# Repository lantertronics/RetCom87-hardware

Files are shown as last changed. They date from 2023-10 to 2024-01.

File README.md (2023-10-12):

# RetCom87-hardware
These are expansion boards for the W65C265SXB development board by Western Design Center developed for the "RetCom87" homebrew computer project by my Retrofuturistic Hardware Vertically Integrated Project team at Georgia Tech. For details, see this YouTube playlist:

https://www.youtube.com/playlist?list=PLOunECWxELQQ03GeMmJSVX49A8VtCcbT9

Atari/Sega controller board: This works! See the Wiki for how to read the controller buttons and the example test code.

Sound board: The YM2149 soundchip board design has been tested on the breadboard, but the actual PCB hasn't been tested yet (I need to order it from JLCPCB). See the example test code.

Video board: The reset pin on TMS9118 is erroneously left disconnected on the PCB; I had to add a bodge wire to hook it to the W65C265SXB reset pin. The TMS9118 board currently sends out bright speckled video. I'm not sure what the issue is: https://youtu.be/yKsjV6f-HKg -- if anyone has any advice, please let me know: lanterma@ece.gatech.edu

These designs are dedicated to the public domain.

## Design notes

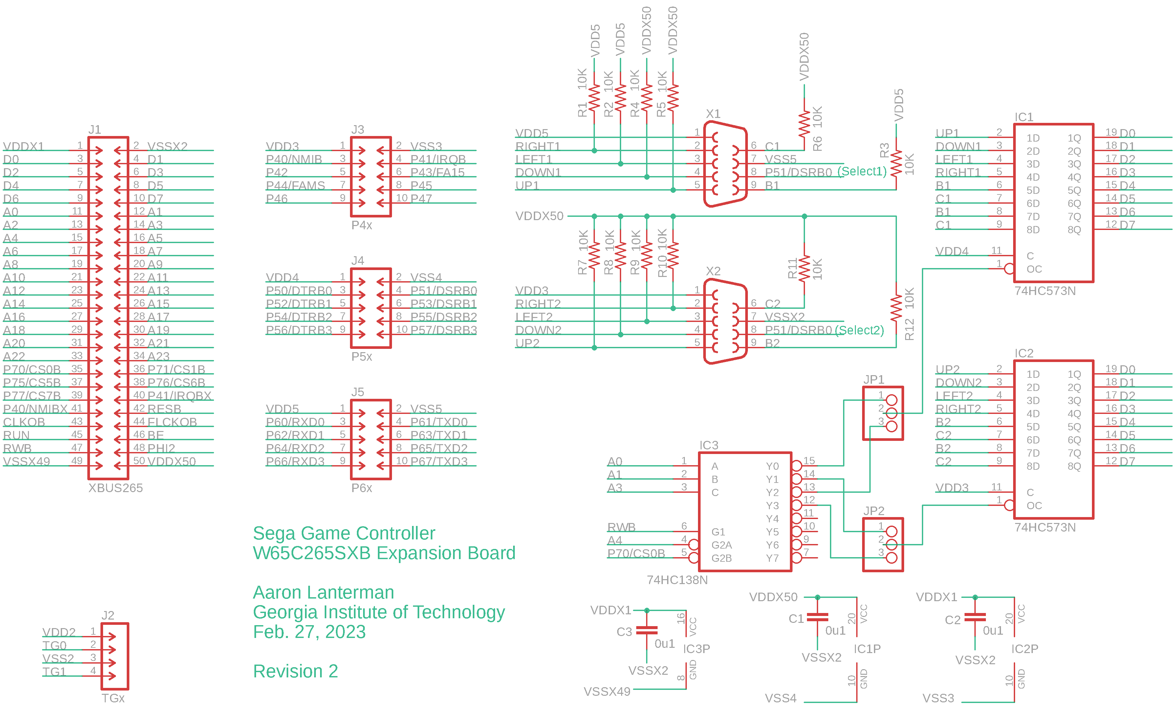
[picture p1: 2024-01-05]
w65c265sxb_controller_rev2_sch.png

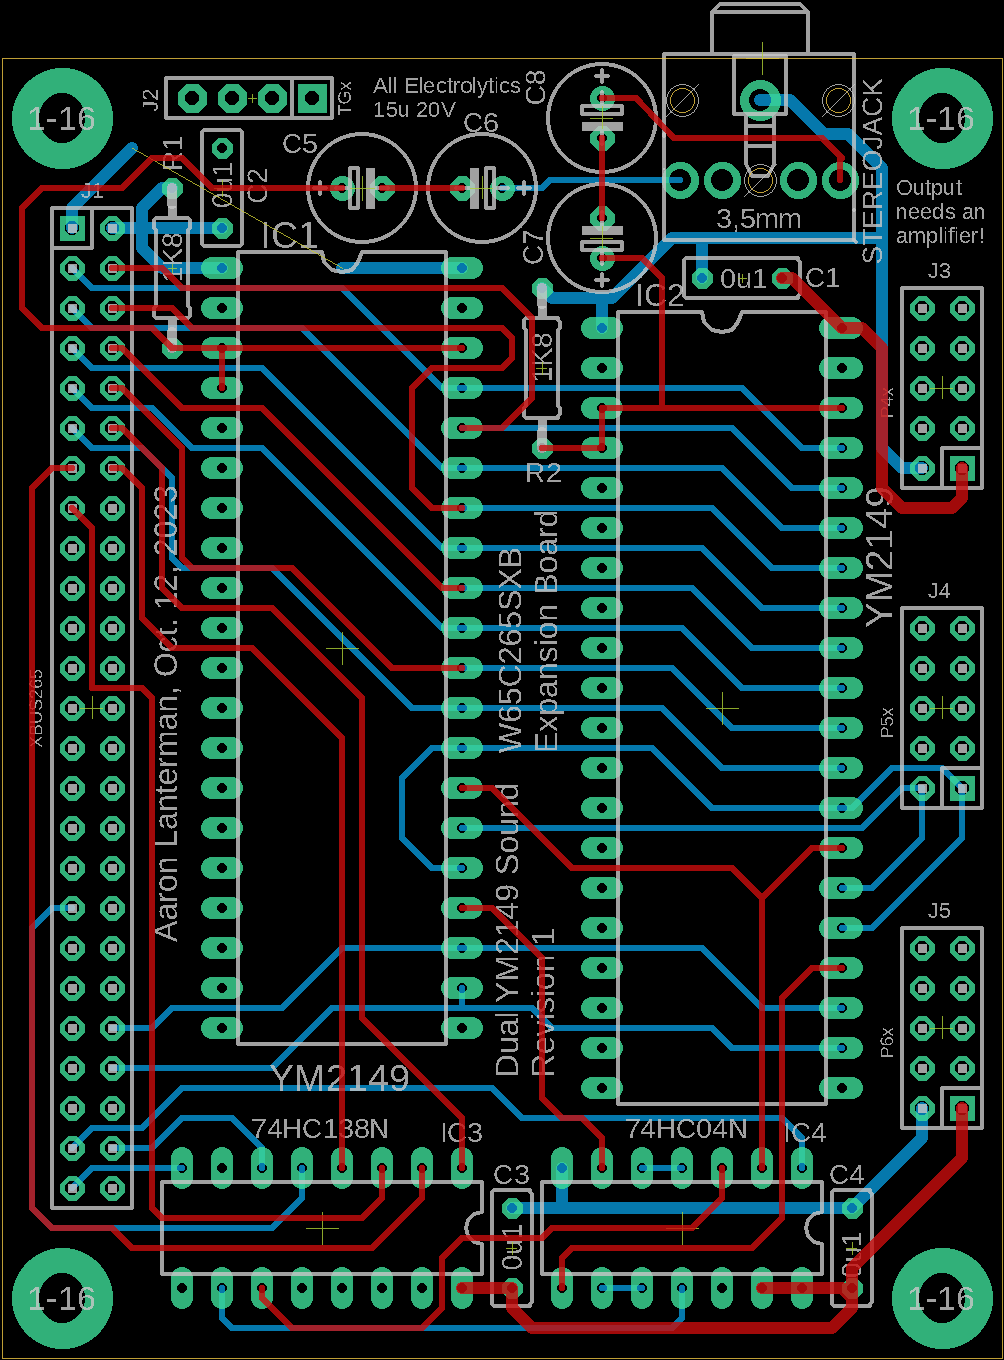
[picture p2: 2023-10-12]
w65c265sxb_ym2149_rev1_brd.png

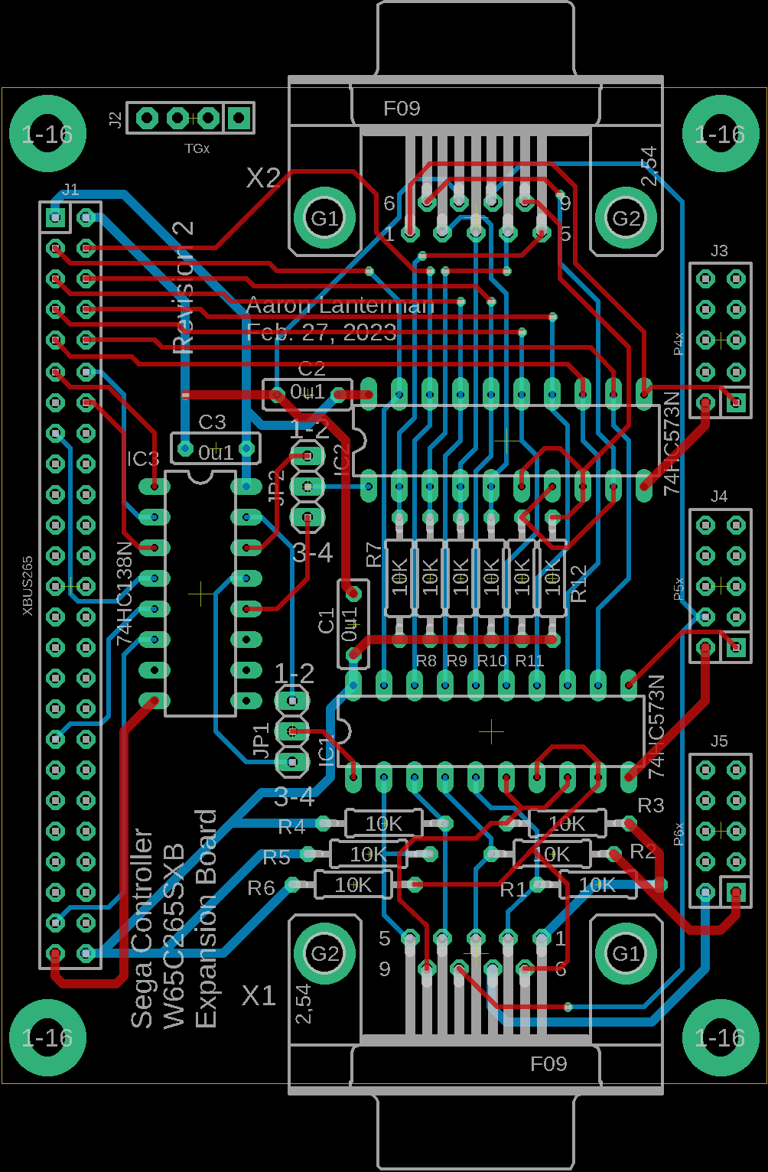
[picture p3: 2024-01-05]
w65c265sxb_controller_rev2_brd.png

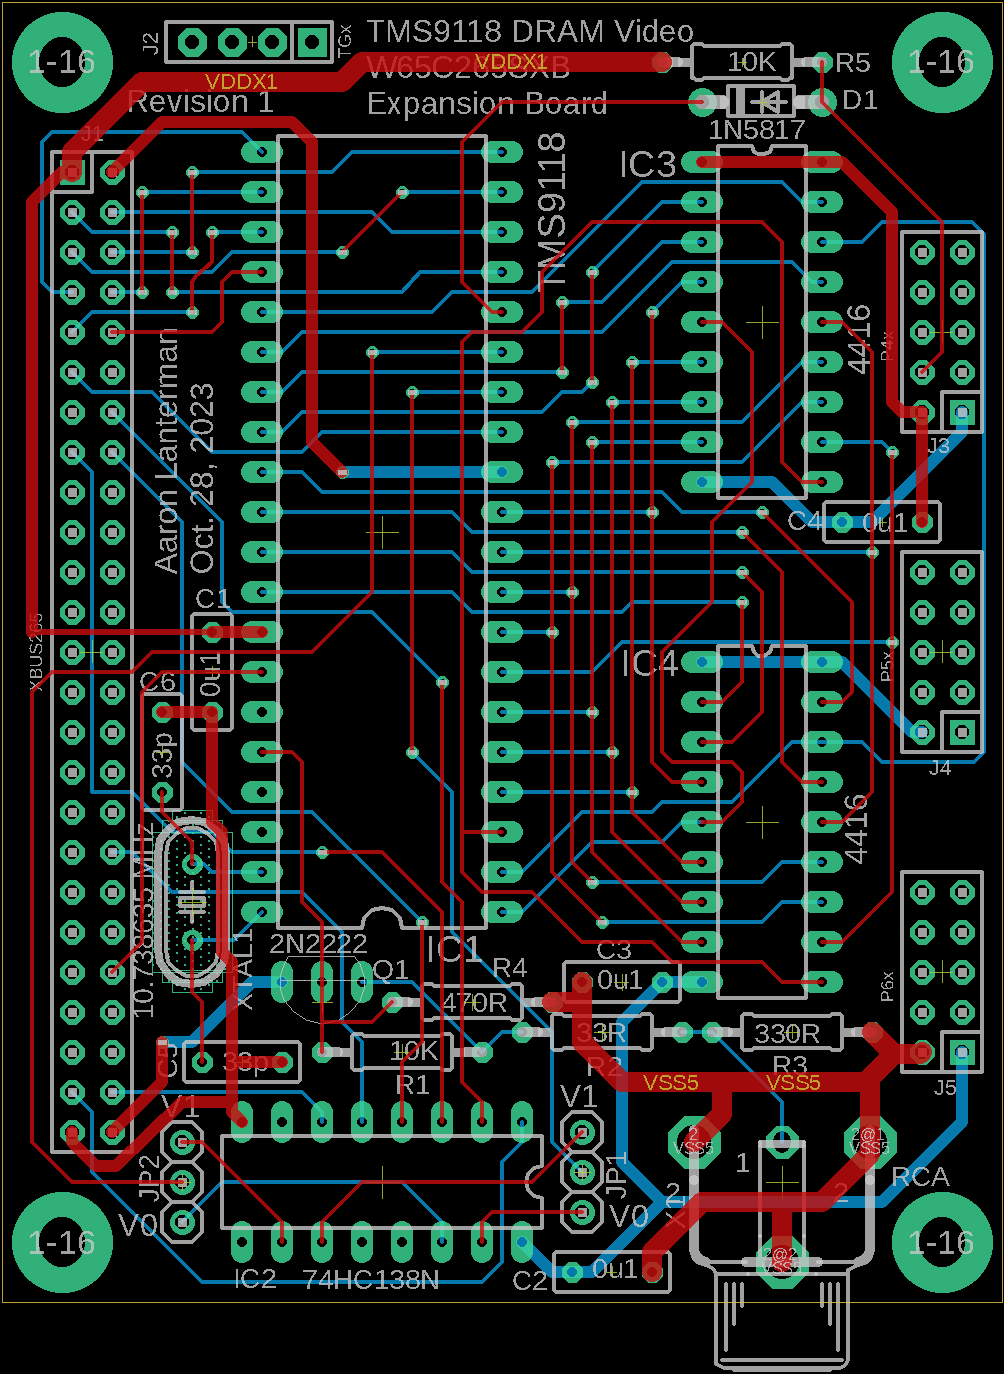
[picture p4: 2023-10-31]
w65c265sxb_tms9118_dram_rev1_brd.png

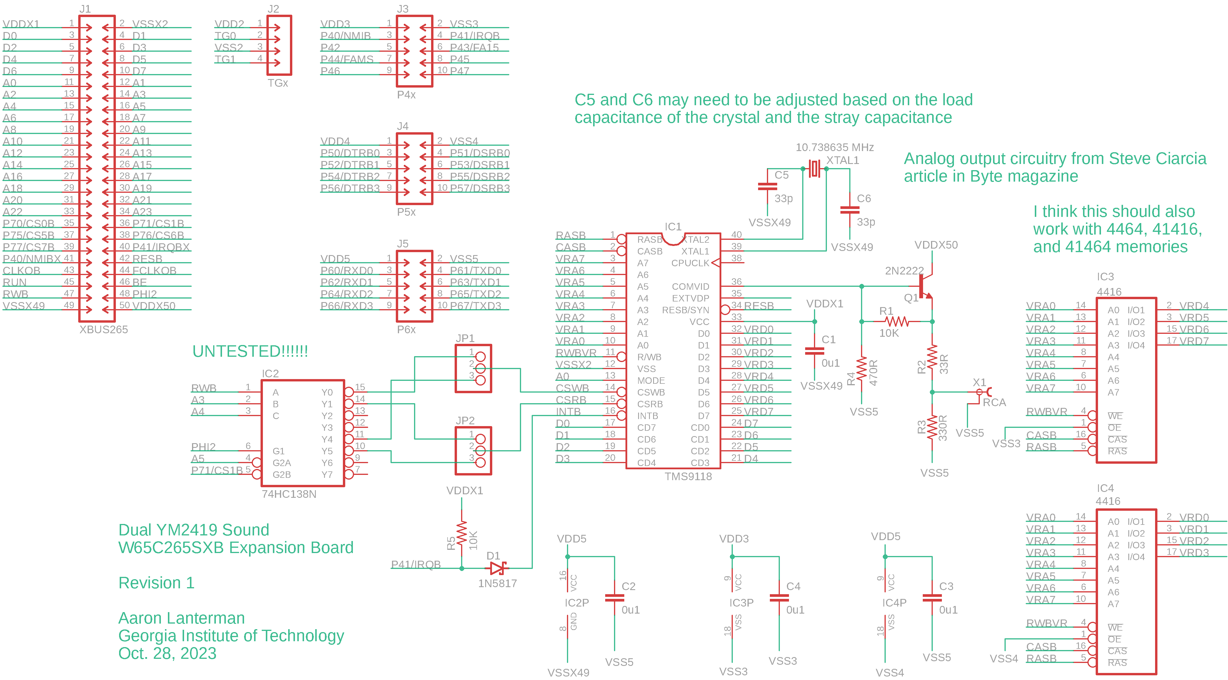
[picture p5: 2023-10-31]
w65c265sxb_tms9118_dram_rev1_sch.png

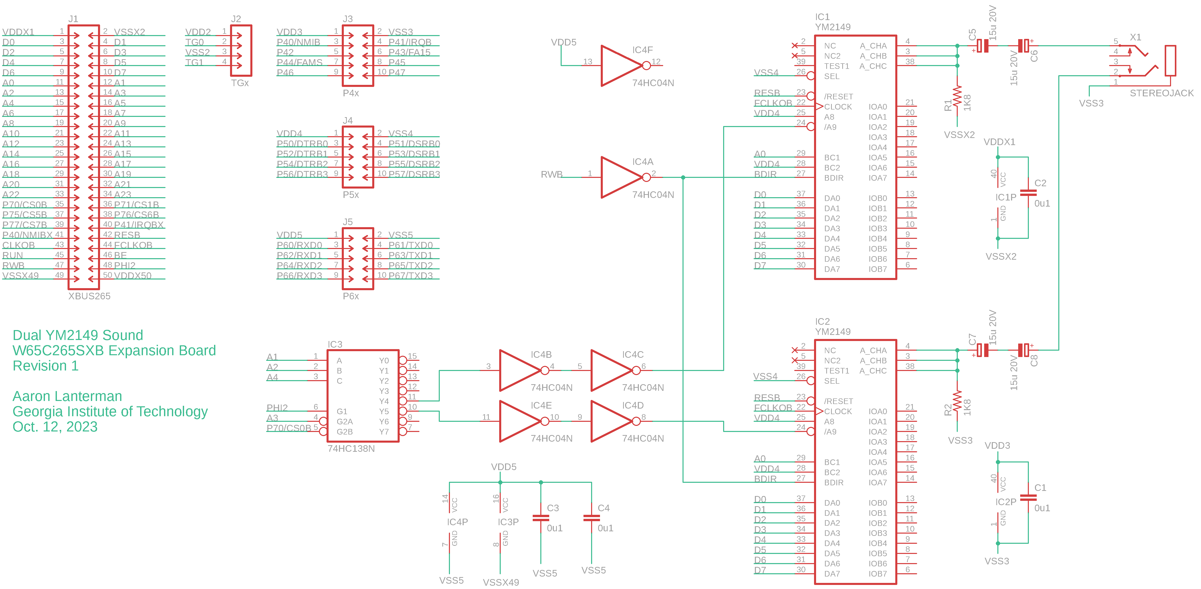
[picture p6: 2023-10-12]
w65c265sxb_ym2149_rev1_sch.png

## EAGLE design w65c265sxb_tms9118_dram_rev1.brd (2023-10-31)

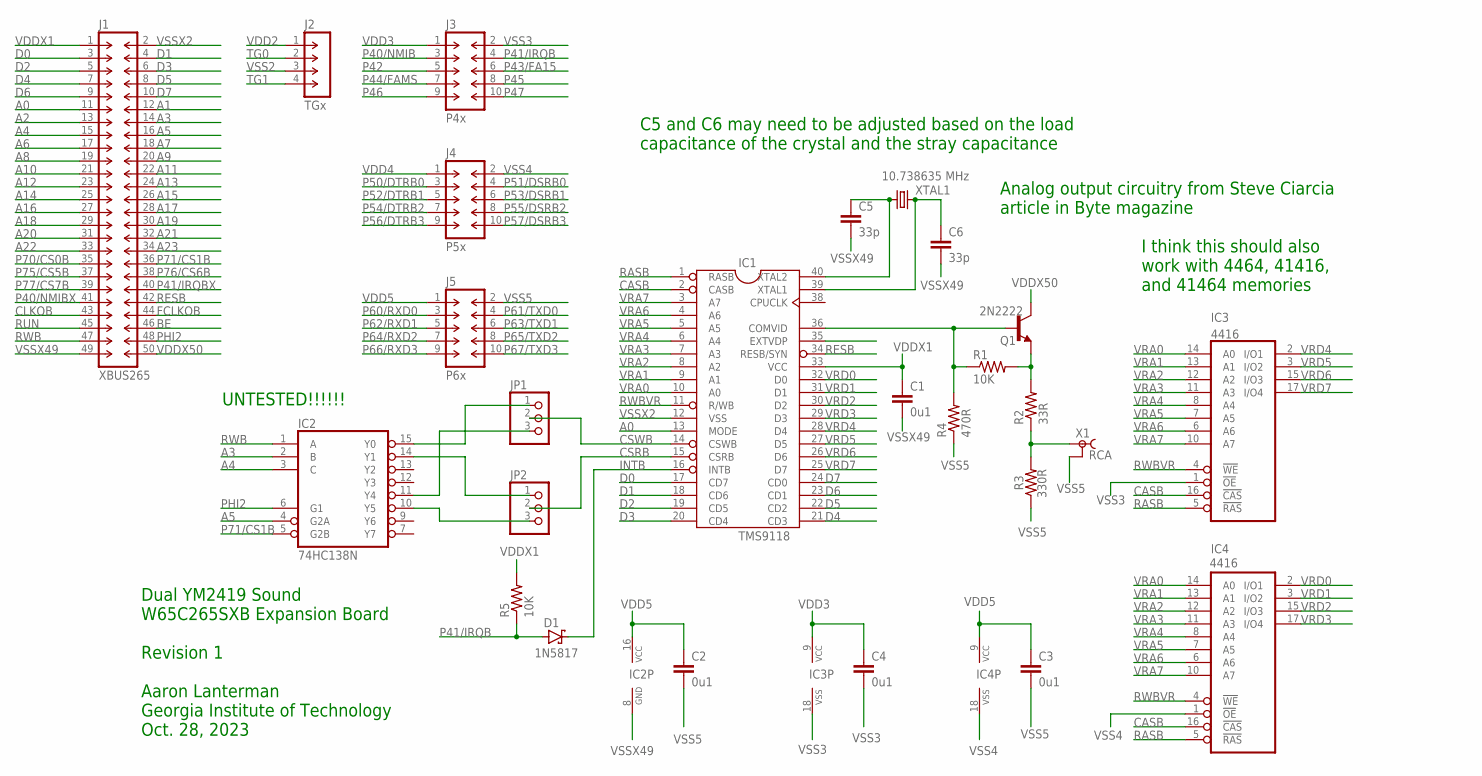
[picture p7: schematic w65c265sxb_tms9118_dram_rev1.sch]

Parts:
C1, C2, C3, C4: 0u1; C050-025X075-AARON
C5, C6: 33p; C050-025X075-AARON
D1: 1N5817-B; DO41-7.6
IC1: TMS9118; DIL40
IC2: 74HC138N; DIL16
IC3, IC4: 41464; DIL18
J1: XBUS265; DIL-100-2X25
J2: TGx; SIP-100-04-40
J3: P4x; DIL-100-2X05
J4: P5x; DIL-100-2X05
J5: P6x; DIL-100-2X05
JP1, JP2: PINHD-1X3; 1X03
Q1: 2N2222; TO92-EBC-OVAL
R1, R5: 10K; 0207/10
R2: 33R; 0207/10
R3: 330R; 0207/10
R4: 470R; 0207/10
X1: RCA; TOBU3
XTAL1: 10.738635 MHz; HC49/S

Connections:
A0: IC1.13 (MODE), J1.11
A1: J1.12
A2: J1.13
A3: IC2.2 (B), J1.14
A4: IC2.3 (C), J1.15
A5: IC2.4 (G2A), J1.16
A6: J1.17
A7: J1.18
A8: J1.19
A9: J1.20
A10: J1.21
A11: J1.22
A12: J1.23
A13: J1.24
A14: J1.25
A15: J1.26
A16: J1.27
A17: J1.28
A18: J1.29
A19: J1.30
A20: J1.31
A21: J1.32
A22: J1.33
A23: J1.34
BE: J1.46
CASB: IC1.2 (CASB), IC3.16 (!CAS), IC4.16 (!CAS)
CLKOB: J1.43
CSRB: IC1.15 (CSRB), JP2.2
CSWB: IC1.14 (CSWB), JP1.2
D0: IC1.17 (CD7), J1.3
D1: IC1.18 (CD6), J1.4
D2: IC1.19 (CD5), J1.5
D3: IC1.20 (CD4), J1.6
D4: IC1.21 (CD3), J1.7
D5: IC1.22 (CD2), J1.8
D6: IC1.23 (CD1), J1.9
D7: IC1.24 (CD0), J1.10
FCLKOB: J1.44
INTB: D1.C, IC1.16 (INTB)
unnamed: IC2.15 (Y0), JP1.1
unnamed: IC2.14 (Y1), JP2.1
unnamed: Q1.E, R1.2, R2.2
unnamed: R2.1, R3.2, X1.1
unnamed: IC2.11 (Y4), JP1.3
unnamed: IC2.10 (Y5), JP2.3
unnamed: IC1.36 (COMVID), Q1.B, R1.1, R4.2
P40/NMIB: J3.3
P40/NMIBX: J1.41
P41/IRQB: D1.A, J3.4, R5.1
P41/IRQBX: J1.40
P42: J3.5
P43/FA15: J3.6
P44/FAMS: J3.7
P45: J3.8
P46: J3.9
P47: J3.10
P50/DTRB0: J4.3
P51/DSRB0: J4.4
P52/DTRB1: J4.5
P53/DSRB1: J4.6
P54/DTRB2: J4.7
P55/DSRB2: J4.8
P56/DTRB3: J4.9
P57/DSRB3: J4.10
P60/RXD0: J5.3
P61/TXD0: J5.4
P62/RXD1: J5.5
P63/TXD1: J5.6
P64/RXD2: J5.7
P65/TXD2: J5.8
P66/RXD3: J5.9
P67/TXD3: J5.10
P70/CS0B: J1.35
P71/CS1B: IC2.5 (G2B), J1.36
P75/CS5B: J1.37
P76/CS6B: J1.38
P77/CS7B: J1.39
PHI2: IC2.6 (G1), J1.48
RASB: IC1.1 (RASB), IC3.5 (!RAS), IC4.5 (!RAS)
RESB: IC1.34 (RESB/SYN), J1.42
RUN: J1.45
RWB: IC2.1 (A), J1.47
RWBVR: IC1.11 (R/WB), IC3.4 (!WE), IC4.4 (!WE)
TG0: J2.2
TG1: J2.4
VDD2: J2.1
VDD3: C4.1, IC3.9 (VCC), J3.1
VDD4: J4.1
VDD5: C2.1, C3.1, IC2.16 (VCC), IC4.9 (VCC), J5.1
VDDX1: C1.1, IC1.33 (VCC), J1.1, R5.2
VDDX50: J1.50, Q1.C
VRA0: IC1.10 (A0), IC3.14 (A0), IC4.14 (A0)
VRA1: IC1.9 (A1), IC3.13 (A1), IC4.13 (A1)
VRA2: IC1.8 (A2), IC3.12 (A2), IC4.12 (A2)
VRA3: IC1.7 (A3), IC3.11 (A3), IC4.11 (A3)
VRA4: IC1.6 (A4), IC3.8 (A4), IC4.8 (A4)
VRA5: IC1.5 (A5), IC3.7 (A5), IC4.7 (A5)
VRA6: IC1.4 (A6), IC3.6 (A6), IC4.6 (A6)
VRA7: IC1.3 (A7), IC3.10 (A7), IC4.10 (A7)
VRD0: IC1.32 (D0), IC4.2 (I/O1)
VRD1: IC1.31 (D1), IC4.3 (I/O2)
VRD2: IC1.30 (D2), IC4.15 (I/O3)
VRD3: IC1.29 (D3), IC4.17 (I/O4)
VRD4: IC1.28 (D4), IC3.2 (I/O1)
VRD5: IC1.27 (D5), IC3.3 (I/O2)
VRD6: IC1.26 (D6), IC3.15 (I/O3)
VRD7: IC1.25 (D7), IC3.17 (I/O4)
VSS2: J2.3
VSS3: C4.2, IC3.1 (!OE), IC3.18 (VSS), J3.2
VSS4: IC4.1 (!OE), IC4.18 (VSS), J4.2
VSS5: C2.2, C3.2, J5.2, R3.1, R4.1, X1.2, X1.2@1 (2), X1.2@2 (2)
VSSX2: IC1.12 (VSS), J1.2
VSSX49: C1.2, C5.2, C6.2, IC2.8 (GND), J1.49
XTAL1: C6.1, IC1.39 (XTAL1), XTAL1.2
XTAL2: C5.1, IC1.40 (XTAL2), XTAL1.1

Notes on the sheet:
Dual YM2419 Sound W65C265SXB Expansion Board Revision 1 Aaron Lanterman Georgia Institute of Technology Oct. 28, 2023
UNTESTED!!!!!!
4416
I think this should also work with 4464, 41416, and 41464 memories
C5 and C6 may need to be adjusted based on the load capacitance of the crystal and the stray capacitance
Analog output circuitry from Steve Ciarcia article in Byte magazine
1N5817

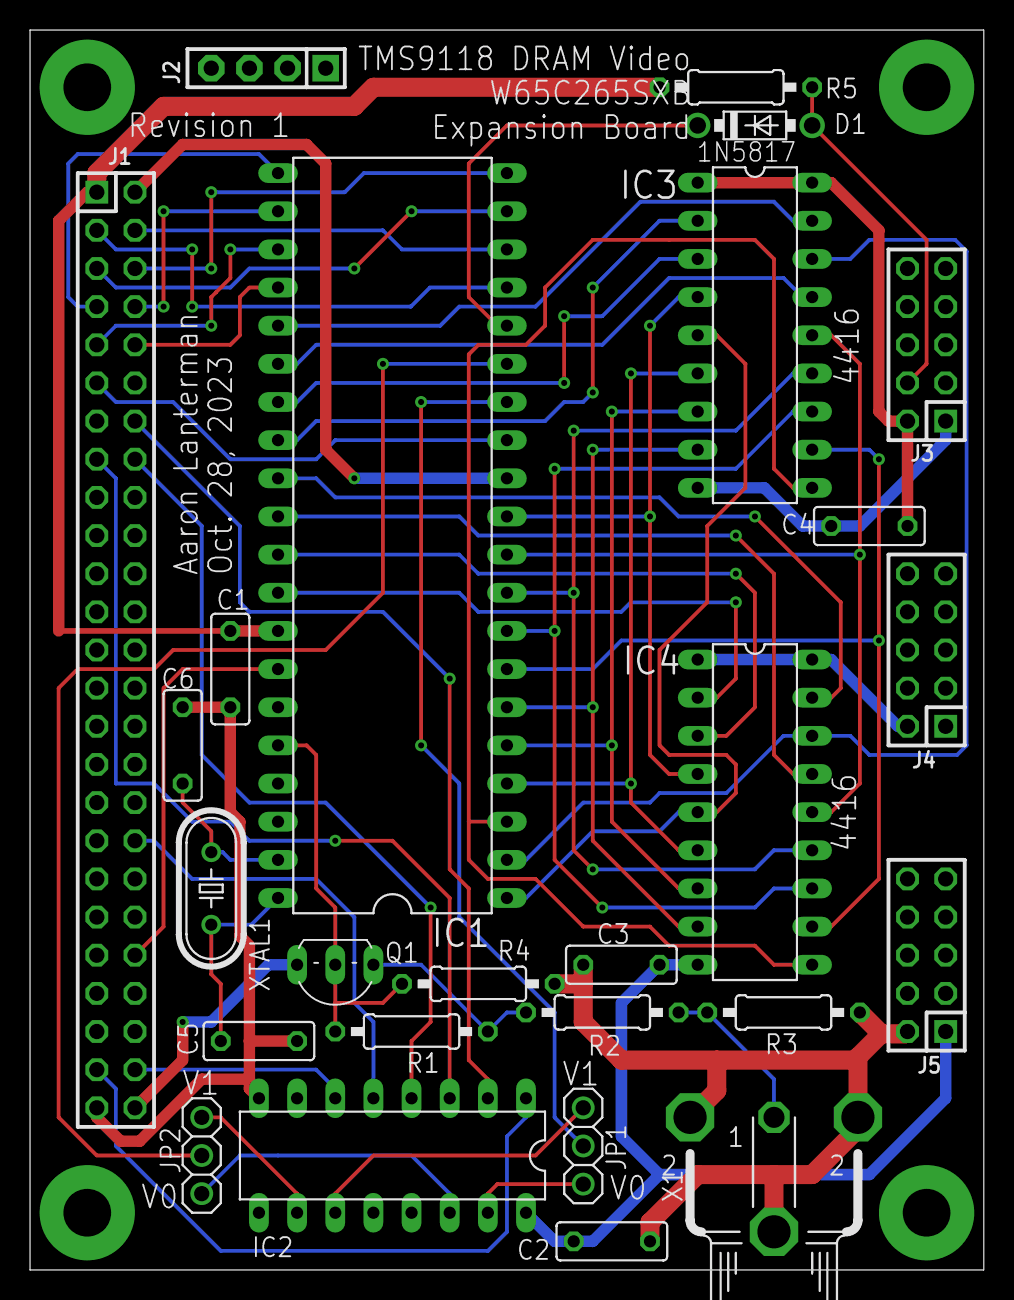
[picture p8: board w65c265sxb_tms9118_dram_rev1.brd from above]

Board: 2 copper layers, 63.5 x 82.5 mm, 26 parts (0 on the bottom side), 57 nets.

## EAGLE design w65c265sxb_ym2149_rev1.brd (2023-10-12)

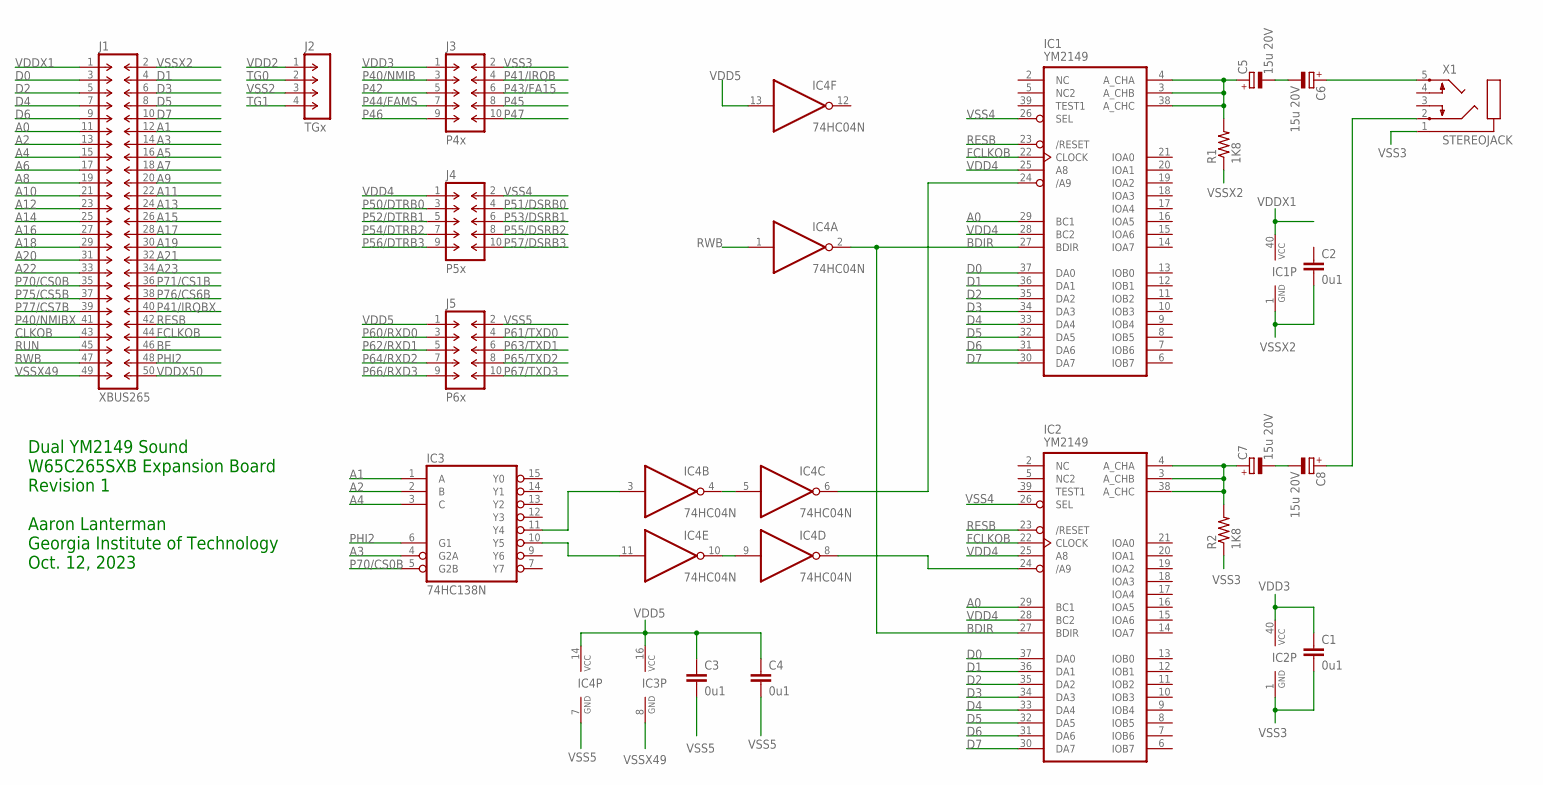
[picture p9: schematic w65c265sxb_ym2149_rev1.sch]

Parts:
C1, C2, C3, C4: 0u1; C050-025X075-AARON
C5, C6, C7, C8: 15u 20V; E2,5-7
IC1, IC2: YM2149; DIL40
IC3: 74HC138N; DIL16
IC4: 74HC04N; DIL14
J1: XBUS265; DIL-100-2X25
J2: TGx; SIP-100-04-40
J3: P4x; DIL-100-2X05
J4: P5x; DIL-100-2X05
J5: P6x; DIL-100-2X05
R1, R2: 1K8; 0207/10
X1: STEREOJACK; STX3100

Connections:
A0: IC1.29 (BC1), IC2.29 (BC1), J1.11
A1: IC3.1 (A), J1.12
A2: IC3.2 (B), J1.13
A3: IC3.4 (G2A), J1.14
A4: IC3.3 (C), J1.15
A5: J1.16
A6: J1.17
A7: J1.18
A8: J1.19
A9: J1.20
A10: J1.21
A11: J1.22
A12: J1.23
A13: J1.24
A14: J1.25
A15: J1.26
A16: J1.27
A17: J1.28
A18: J1.29
A19: J1.30
A20: J1.31
A21: J1.32
A22: J1.33
A23: J1.34
BDIR: IC1.27 (BDIR), IC2.27 (BDIR), IC4.2 (O)
BE: J1.46
CLKOB: J1.43
D0: IC1.37 (DA0), IC2.37 (DA0), J1.3
D1: IC1.36 (DA1), IC2.36 (DA1), J1.4
D2: IC1.35 (DA2), IC2.35 (DA2), J1.5
D3: IC1.34 (DA3), IC2.34 (DA3), J1.6
D4: IC1.33 (DA4), IC2.33 (DA4), J1.7
D5: IC1.32 (DA5), IC2.32 (DA5), J1.8
D6: IC1.31 (DA6), IC2.31 (DA6), J1.9
D7: IC1.30 (DA7), IC2.30 (DA7), J1.10
FCLKOB: IC1.22 (CLOCK), IC2.22 (CLOCK), J1.44
unnamed: IC3.11 (Y4), IC4.3 (I)
unnamed: IC4.4 (O), IC4.5 (I)
unnamed: IC4.9 (I), IC4.10 (O)
unnamed: IC1.24 (/A9), IC4.6 (O)
unnamed: IC3.10 (Y5), IC4.11 (I)
unnamed: C5.+, IC1.3 (A_CHB), IC1.4 (A_CHA), IC1.38 (A_CHC), R1.2
unnamed: C7.+, IC2.3 (A_CHB), IC2.4 (A_CHA), IC2.38 (A_CHC), R2.2
unnamed: IC2.24 (/A9), IC4.8 (O)
unnamed: C5.-, C6.-
unnamed: C7.-, C8.-
unnamed: C6.+, X1.5
unnamed: C8.+, X1.2
P40/NMIB: J3.3
P40/NMIBX: J1.41
P41/IRQB: J3.4
P41/IRQBX: J1.40
P42: J3.5
P43/FA15: J3.6
P44/FAMS: J3.7
P45: J3.8
P46: J3.9
P47: J3.10
P50/DTRB0: J4.3
P51/DSRB0: J4.4
P52/DTRB1: J4.5
P53/DSRB1: J4.6
P54/DTRB2: J4.7
P55/DSRB2: J4.8
P56/DTRB3: J4.9
P57/DSRB3: J4.10
P60/RXD0: J5.3
P61/TXD0: J5.4
P62/RXD1: J5.5
P63/TXD1: J5.6
P64/RXD2: J5.7
P65/TXD2: J5.8
P66/RXD3: J5.9
P67/TXD3: J5.10
P70/CS0B: IC3.5 (G2B), J1.35
P71/CS1B: J1.36
P75/CS5B: J1.37
P76/CS6B: J1.38
P77/CS7B: J1.39
PHI2: IC3.6 (G1), J1.48
RESB: IC1.23 (/RESET), IC2.23 (/RESET), J1.42
RUN: J1.45
RWB: IC4.1 (I), J1.47
TG0: J2.2
TG1: J2.4
VDD2: J2.1
VDD3: C1.1, IC2.40 (VCC), J3.1
VDD4: IC1.25 (A8), IC1.28 (BC2), IC2.25 (A8), IC2.28 (BC2), J4.1
VDD5: C3.1, C4.1, IC3.16 (VCC), IC4.13 (I), IC4.14 (VCC), J5.1
VDDX1: IC1.40 (VCC), J1.1
VDDX50: J1.50
VSS2: J2.3
VSS3: C1.2, IC2.1 (GND), J3.2, R2.1, X1.1
VSS4: IC1.26 (SEL), IC2.26 (SEL), J4.2
VSS5: C3.2, C4.2, IC4.7 (GND), J5.2
VSSX2: C2.2, IC1.1 (GND), J1.2, R1.1
VSSX49: IC3.8 (GND), J1.49

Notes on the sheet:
Dual YM2149 Sound W65C265SXB Expansion Board Revision 1 Aaron Lanterman Georgia Institute of Technology Oct. 12, 2023

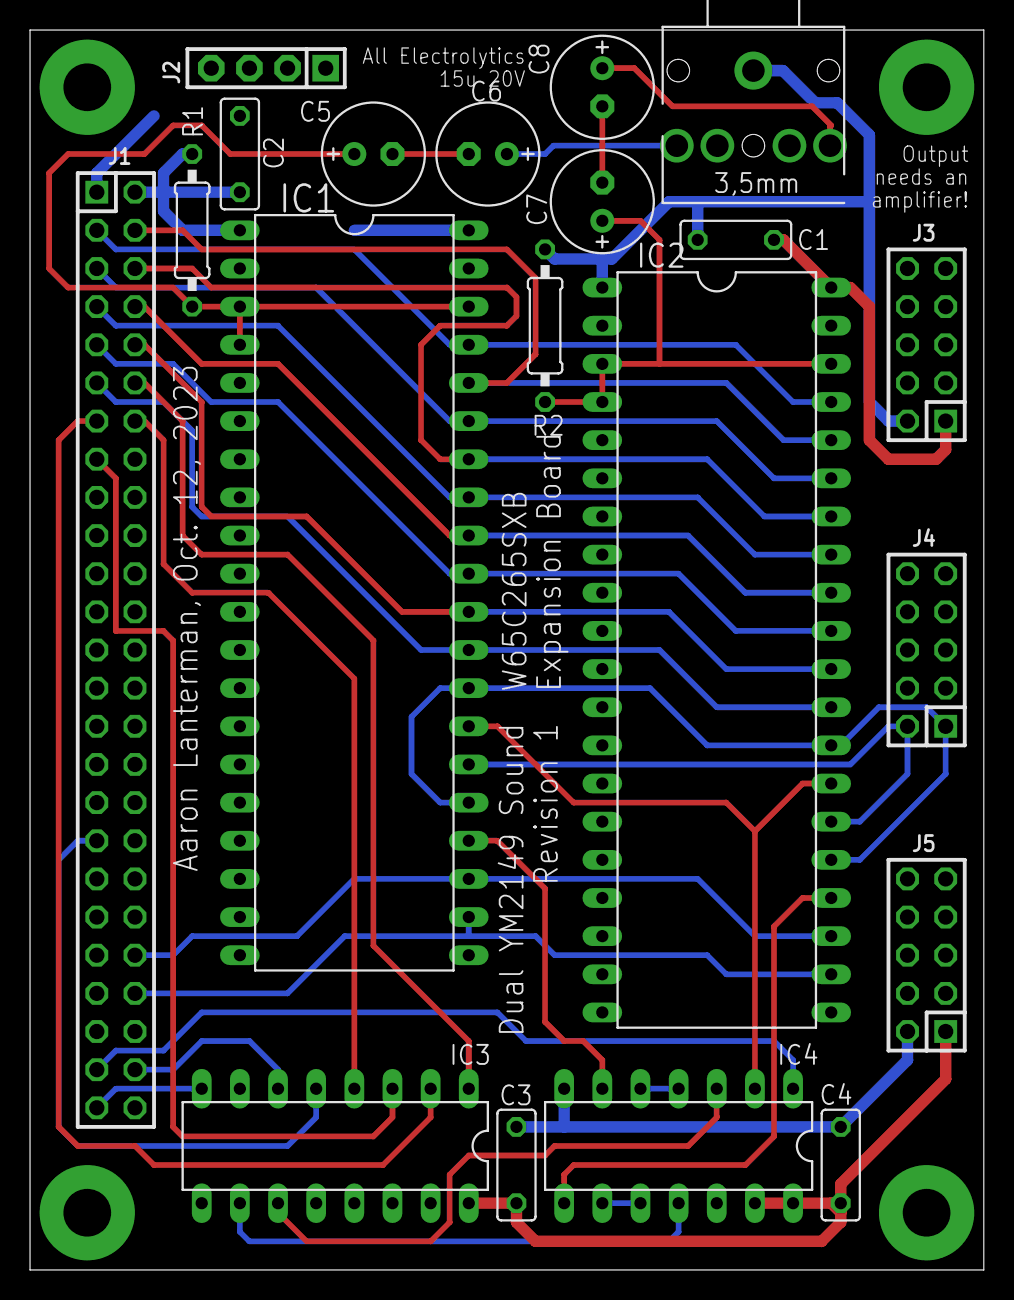
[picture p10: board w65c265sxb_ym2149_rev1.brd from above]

Board: 2 copper layers, 63.5 x 82.5 mm, 20 parts (0 on the bottom side), 40 nets.

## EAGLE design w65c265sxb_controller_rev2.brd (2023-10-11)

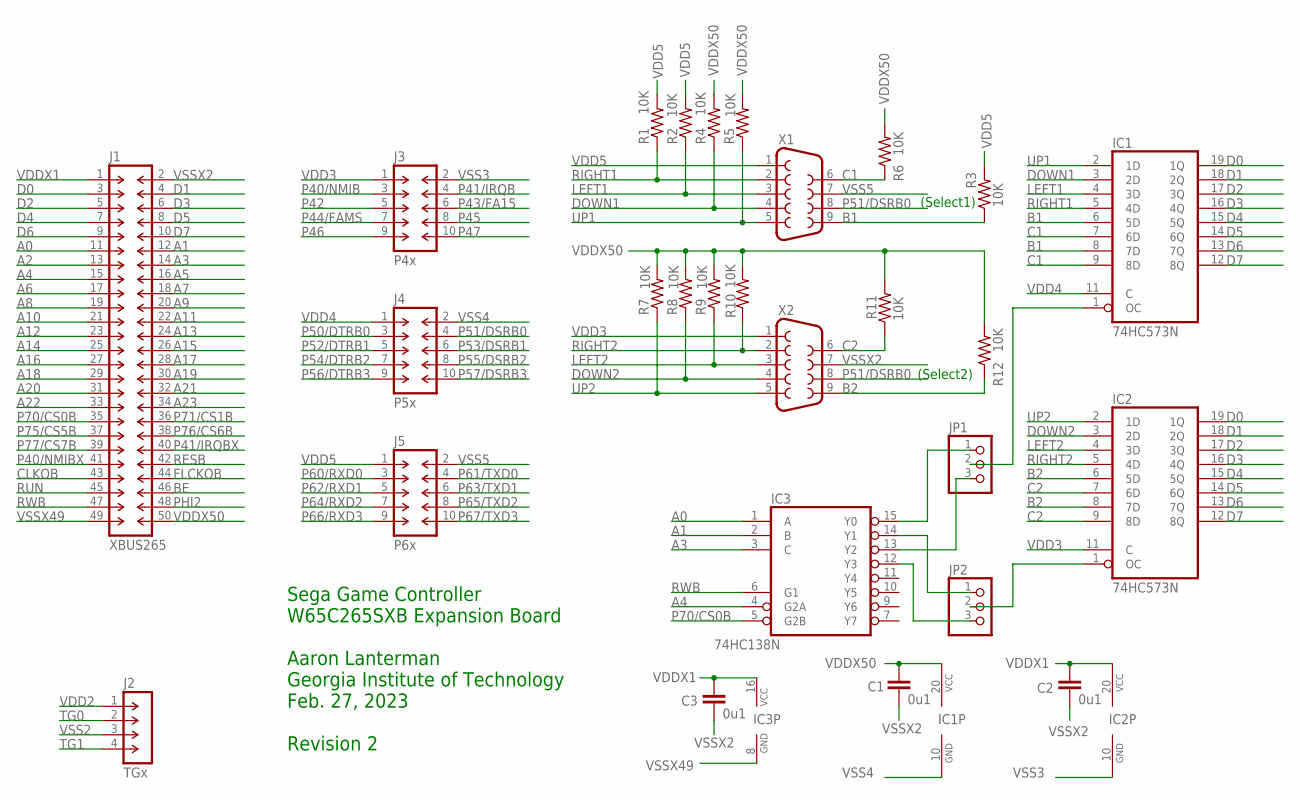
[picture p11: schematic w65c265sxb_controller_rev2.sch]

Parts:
C1, C2, C3: 0u1; C050-025X075-AARON
IC1, IC2: 74HC573N; DIL20
IC3: 74HC138N; DIL16
J1: XBUS265; DIL-100-2X25
J2: TGx; SIP-100-04-40
J3: P4x; DIL-100-2X05
J4: P5x; DIL-100-2X05
J5: P6x; DIL-100-2X05
JP1, JP2: PINHD-1X3; 1X03
R1, R2, R3, R4, R5, R6, R7, R8, R9, R10, R11, R12: 10K; 0207/10
X1, X2: F09HP

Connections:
A0: IC3.1 (A), J1.11
A1: IC3.2 (B), J1.12
A2: J1.13
A3: IC3.3 (C), J1.14
A4: IC3.4 (G2A), J1.15
A5: J1.16
A6: J1.17
A7: J1.18
A8: J1.19
A9: J1.20
A10: J1.21
A11: J1.22
A12: J1.23
A13: J1.24
A14: J1.25
A15: J1.26
A16: J1.27
A17: J1.28
A18: J1.29
A19: J1.30
A20: J1.31
A21: J1.32
A22: J1.33
A23: J1.34
B1: IC1.6 (5D), IC1.8 (7D), R3.1, X1.9
B2: IC2.6 (5D), IC2.8 (7D), R12.1, X2.9
BE: J1.46
C1: IC1.7 (6D), IC1.9 (8D), R6.1, X1.6
C2: IC2.7 (6D), IC2.9 (8D), R11.1, X2.6
CLKOB: J1.43
D0: IC1.19 (1Q), IC2.19 (1Q), J1.3
D1: IC1.18 (2Q), IC2.18 (2Q), J1.4
D2: IC1.17 (3Q), IC2.17 (3Q), J1.5
D3: IC1.16 (4Q), IC2.16 (4Q), J1.6
D4: IC1.15 (5Q), IC2.15 (5Q), J1.7
D5: IC1.14 (6Q), IC2.14 (6Q), J1.8
D6: IC1.13 (7Q), IC2.13 (7Q), J1.9
D7: IC1.12 (8Q), IC2.12 (8Q), J1.10
DOWN1: IC1.3 (2D), R4.1, X1.4
DOWN2: IC2.3 (2D), R8.1, X2.4
FLCKOB: J1.44
LEFT1: IC1.4 (3D), R2.1, X1.3
LEFT2: IC2.4 (3D), R9.1, X2.3
unnamed: IC3.15 (Y0), JP1.1
unnamed: IC3.13 (Y2), JP1.3
unnamed: IC1.1 (OC), JP1.2
unnamed: IC3.14 (Y1), JP2.1
unnamed: IC3.12 (Y3), JP2.3
unnamed: IC2.1 (OC), JP2.2
P40/NMIB: J3.3
P40/NMIBX: J1.41
P41/IRQB: J3.4
P41/IRQBX: J1.40
P42: J3.5
P43/FA15: J3.6
P44/FAMS: J3.7
P45: J3.8
P46: J3.9
P47: J3.10
P50/DTRB0: J4.3
P51/DSRB0: J4.4, X1.8, X2.8
P52/DTRB1: J4.5
P53/DSRB1: J4.6
P54/DTRB2: J4.7
P55/DSRB2: J4.8
P56/DTRB3: J4.9
P57/DSRB3: J4.10
P60/RXD0: J5.3
P61/TXD0: J5.4
P62/RXD1: J5.5
P63/TXD1: J5.6
P64/RXD2: J5.7
P65/TXD2: J5.8
P66/RXD3: J5.9
P67/TXD3: J5.10
P70/CS0B: IC3.5 (G2B), J1.35
P71/CS1B: J1.36
P75/CS5B: J1.37
P76/CS6B: J1.38
P77/CS7B: J1.39
PHI2: J1.48
RESB: J1.42
RIGHT1: IC1.5 (4D), R1.1, X1.2
RIGHT2: IC2.5 (4D), R10.1, X2.2
RUN: J1.45
RWB: IC3.6 (G1), J1.47
TG0: J2.2
TG1: J2.4
UP1: IC1.2 (1D), R5.1, X1.5
UP2: IC2.2 (1D), R7.1, X2.5
VDD2: J2.1
VDD3: IC2.11 (C), J3.1, X2.1
VDD4: IC1.11 (C), J4.1
VDD5: J5.1, R1.2, R2.2, R3.2, X1.1
VDDX1: C2.1, C3.1, IC2.20 (VCC), IC3.16 (VCC), J1.1
VDDX50: C1.1, IC1.20 (VCC), J1.50, R4.2, R5.2, R6.2, R7.2, R8.2, R9.2, R10.2, R11.2, R12.2
VSS2: J2.3
VSS3: IC2.10 (GND), J3.2
VSS4: IC1.10 (GND), J4.2
VSS5: J5.2, X1.7
VSSX2: C1.2, C2.2, C3.2, J1.2, X2.7
VSSX49: IC3.8 (GND), J1.49

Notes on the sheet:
Sega Game Controller W65C265SXB Expansion Board Aaron Lanterman Georgia Institute of Technology Feb. 27, 2023 Revision 2
(Select1)
(Select2)

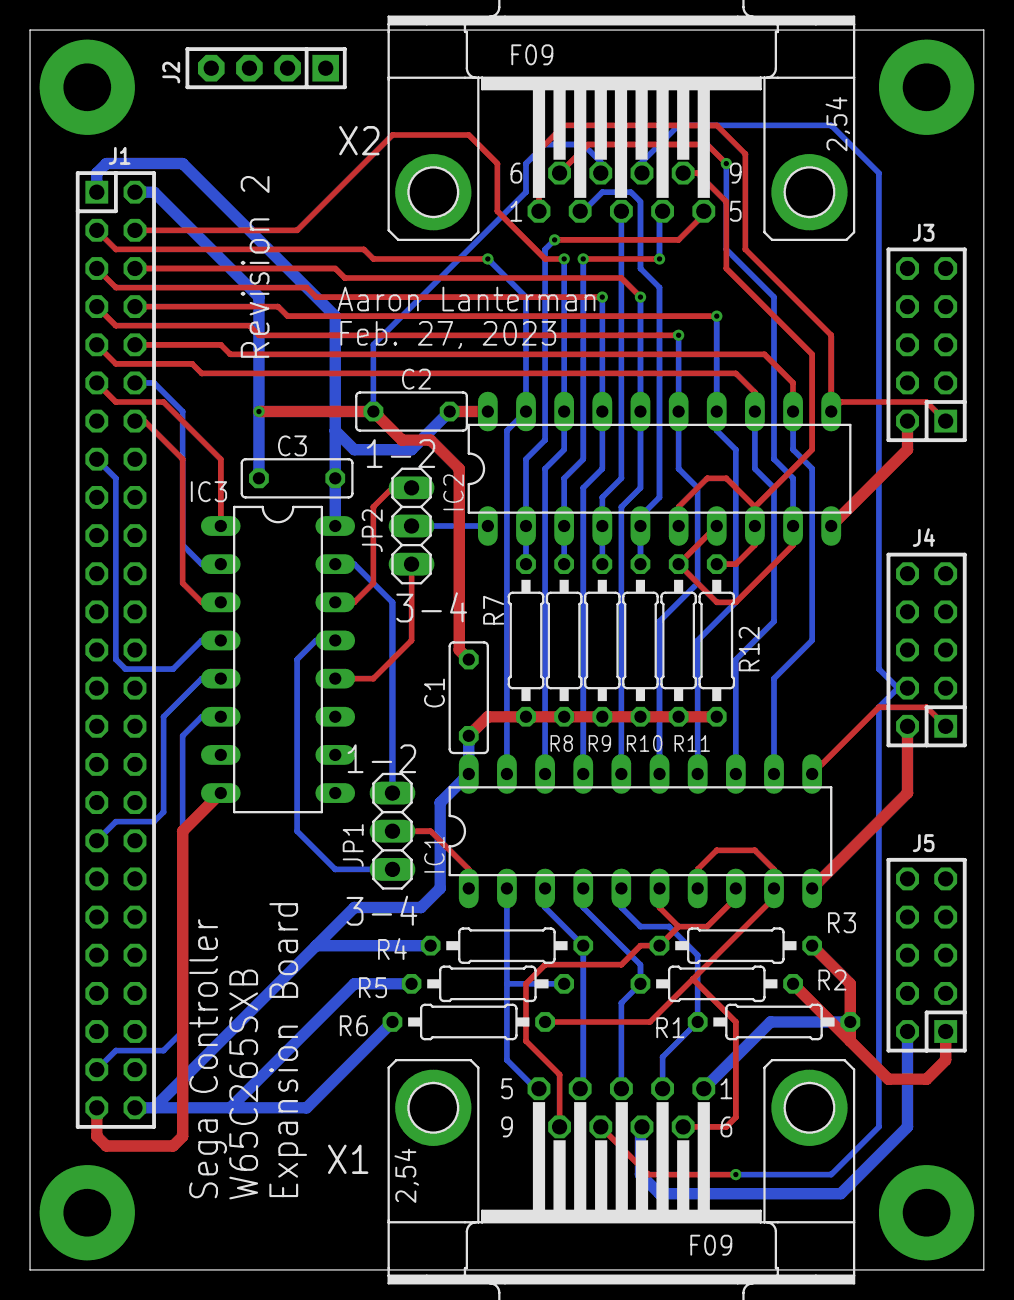
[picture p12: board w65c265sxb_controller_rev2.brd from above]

Board: 2 copper layers, 63.5 x 82.5 mm, 27 parts (0 on the bottom side), 43 nets.

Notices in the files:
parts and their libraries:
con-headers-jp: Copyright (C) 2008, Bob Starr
